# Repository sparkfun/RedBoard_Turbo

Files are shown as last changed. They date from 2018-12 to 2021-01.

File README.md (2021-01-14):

SparkFun RedBoard Turbo
========================================

SparkFun RedBoard Turbo

[*SparkFun RedBoard Turbo (DEV-14812)*](https://www.sparkfun.com/products/14812)

The RedBoard Turbo is an Arduino-sized breakout for the Atmel [ATSAMD21G18](http://www.atmel.com/devices/ATSAMD21G18A.aspx), a 32-bit ARM Cortex-M0+ processor with 4MB external flash, 32KB SRAM, and an operating speed of up to 48MHz. The SAMD21 is compatible with the Arduino IDE, and libraries for the Arduino Zero. With the UF2 bootloader, programming is easier than ever!

Repository Contents
-------------------

* **/Documentation** - Data sheets, additional product information
* **/Firmware** - UF2 Bootloader
* **/Hardware** - Eagle design files (.brd, .sch)
* **/Production** - Production panel files (.brd)

Documentation
--------------
* **[SparkFun Arduino Boards](https://github.com/sparkfun/Arduino_Boards)** - Arduino Boards.
* **[Hookup Guide](https://learn.sparkfun.com/tutorials/redboard-turbo-hookup-guide)** - Basic hookup guide for the RedBoard Turbo.
* **[SparkFun Fritzing Repo](https://github.com/sparkfun/Fritzing_Parts/blob/master/products/14812_sfe_redboard_turbo.fzpz)** - Fritzing diagrams for SparkFun products.
* **[SparkFun Graphical Datasheets](https://github.com/sparkfun/Graphical_Datasheets)** - Graphical Datasheets for various SparkFun products.

License Information
-------------------

This product is _**open source**_! 

Please review the LICENSE.md file for license information. 

If you have any questions or concerns on licensing, please contact technical support on our [SparkFun forums](https://forum.sparkfun.com/viewforum.php?f=152).

Distributed as-is; no warranty is given.

- Your friends at SparkFun.

_<COLLABORATION CREDIT>_

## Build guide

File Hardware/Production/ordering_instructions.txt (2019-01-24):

panel size, 204x175mm
PCB thickness, 1.6mm
number of layers, 2
soldermask color, Red
silkscreen color, White
oz copper, 1oz
finish, HASL lead free
stencils, none
pcs per panel, 9

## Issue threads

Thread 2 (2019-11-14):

dtostrf missing RedBoard_Turbo when it exists for Arduino Uno

alohawild, 2019-11-14:
I discovered I could not compile my code that coverts numbers to string. I had to instead find the code on the Internet and build it in myself. I think this should be built in.

Here is the code:

```
char * dtostrf(double number, signed char width, unsigned char prec, char *s) {

    if(isnan(number)) {
        strcpy(s, "nan");
        return s;
    }
    if(isinf(number)) {
        strcpy(s, "inf");
        return s;
    }

    if(number > 4294967040.0 || number < -4294967040.0) {
        strcpy(s, "ovf");
        return s;
    }
    char* out = s;
    // Handle negative numbers
    if(number < 0.0) {
        *out = '-';
        ++out;
        number = -number;
    }

    // Round correctly so that print(1.999, 2) prints as "2.00"
    double rounding = 0.5;
    for(uint8_t i = 0; i < prec; ++i)
        rounding /= 10.0;

    number += rounding;

    // Extract the integer part of the number and print it
    unsigned long int_part = (unsigned long) number;
    double remainder = number - (double) int_part;
    out += sprintf(out, "%d", int_part);

    // Print the decimal point, but only if there are digits beyond
    if(prec > 0) {
        *out = '.';
        ++out;
    }

    while(prec-- > 0) {
        remainder *= 10.0;
        if((int)remainder == 0){
                *out = '0';
                 ++out;
        }
    }
    sprintf(out, "%d", (int) remainder);

    return s;
}
```

awende, 2019-11-14:
The RedBoard Turbo uses the [uf2 bootloader](https://github.com/microsoft/uf2-samdx1) which was created and maintained by Microsoft. But looking into the issue I found that the dtostrf() function does not seem to work with any of the SAMD boards (tested with the Arduino/Genuino Zero board definition).

To get it working, you just need to add the library at the top of your sketch with any other libraries you may be using. Specifically, adding the following at the top of your sketch will get it to work.

`#include <avr/dtostrf.h>`

alohawild, 2019-11-14:
I like that better than copying in the code. Thanks for looking into this so fast. We can leave this as the solution so if anyone else has the issue they can see this here

Closed 2019-11-14.

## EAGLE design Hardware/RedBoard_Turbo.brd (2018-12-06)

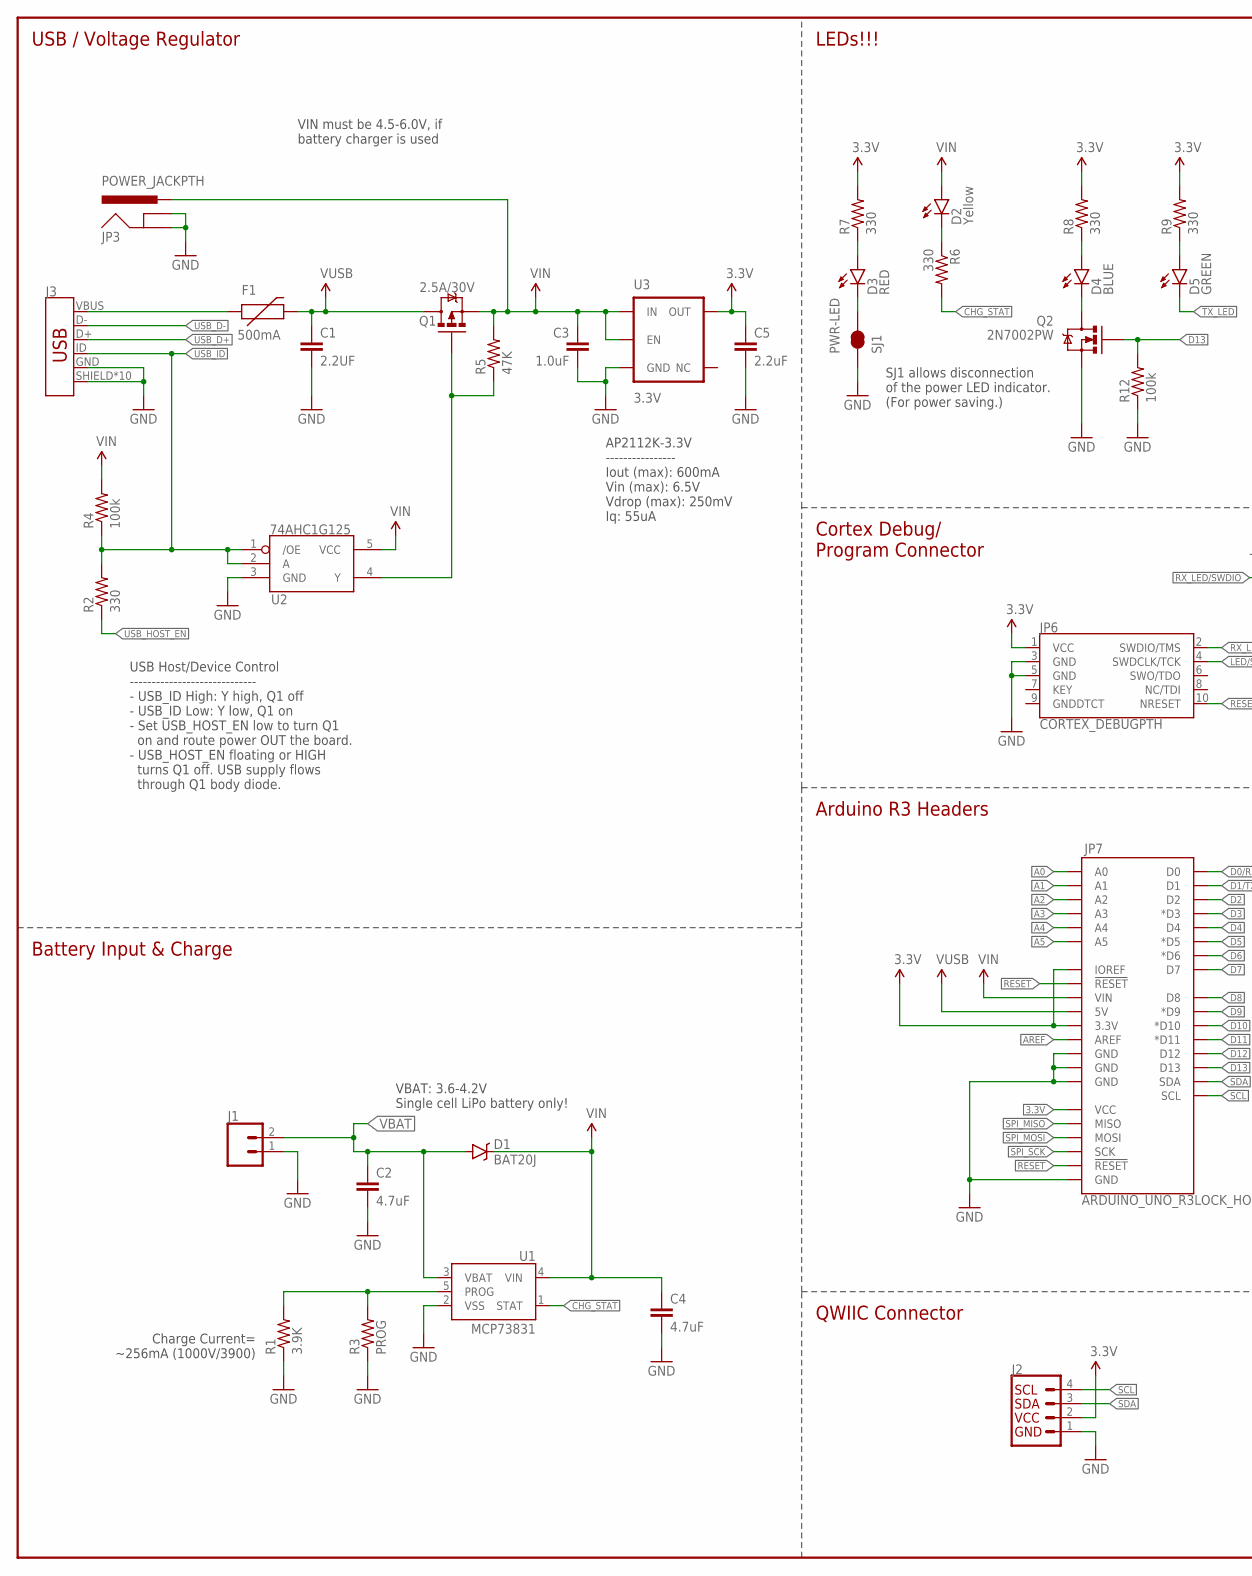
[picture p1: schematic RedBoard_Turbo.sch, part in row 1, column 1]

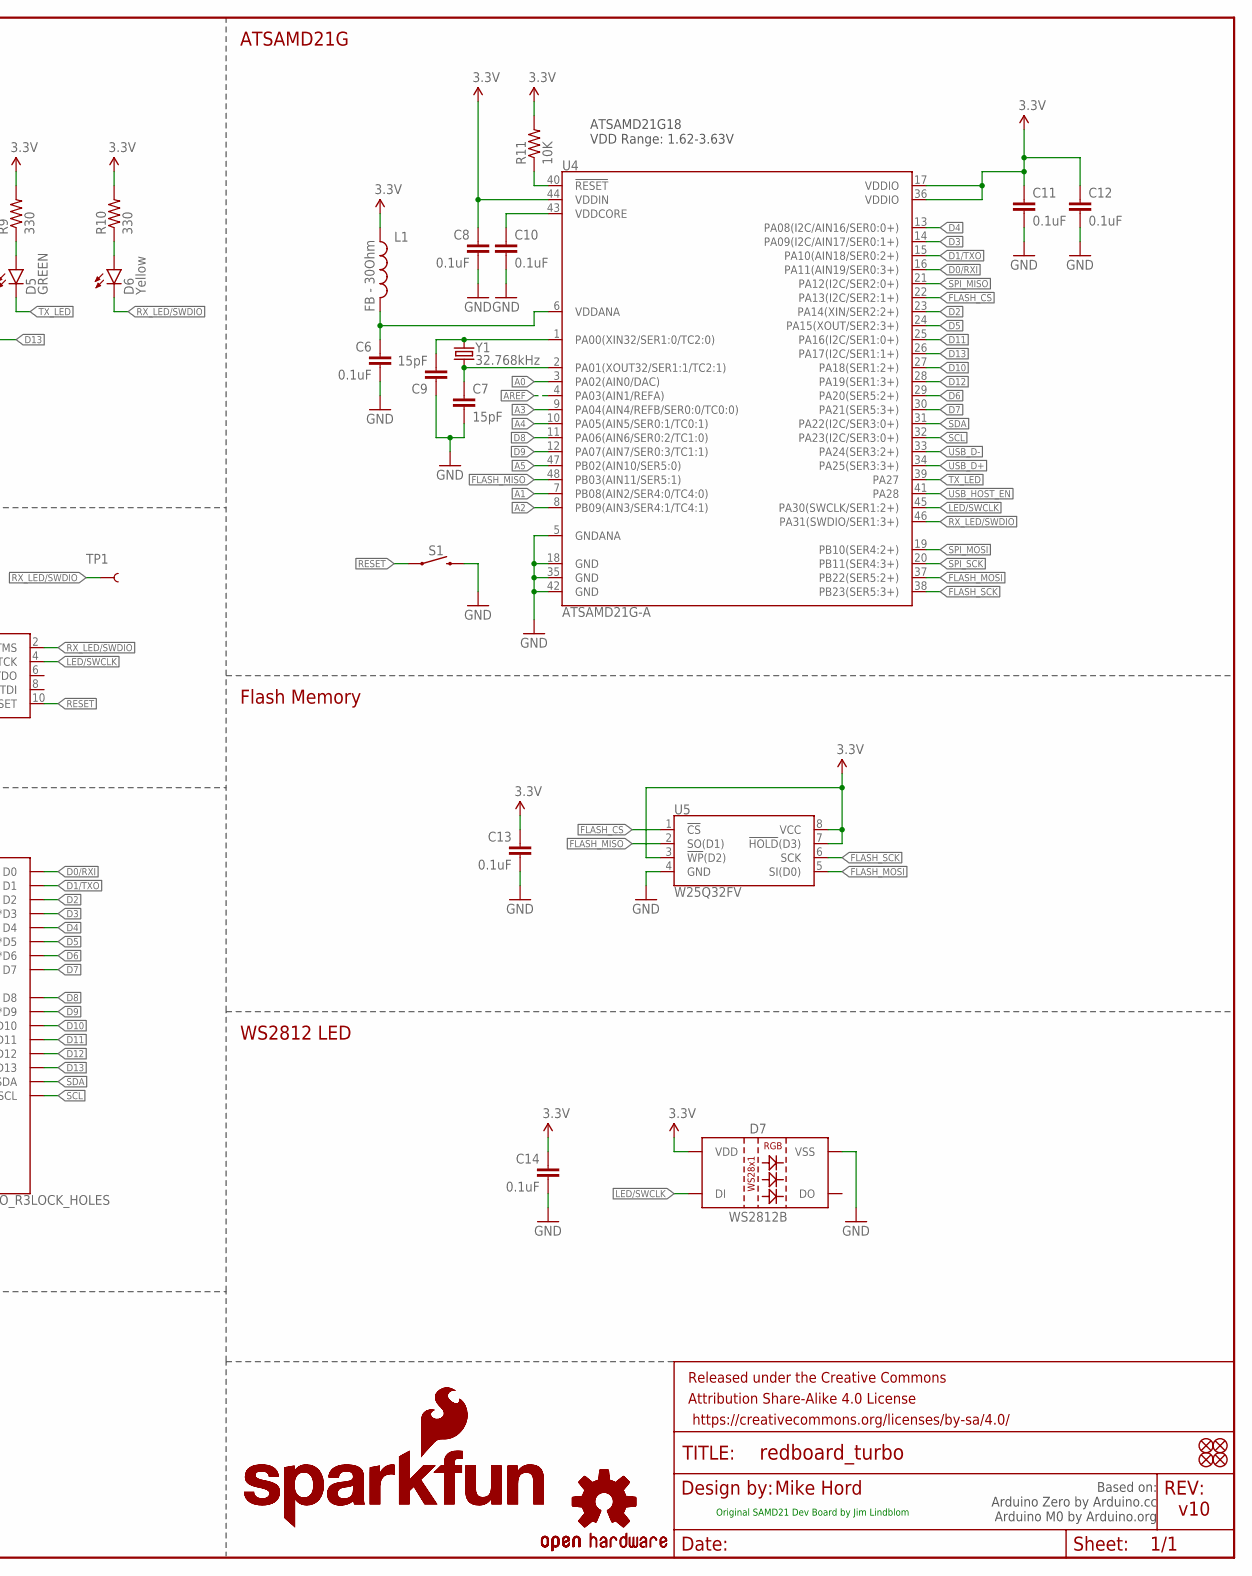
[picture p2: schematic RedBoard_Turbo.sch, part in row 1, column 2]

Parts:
C1: 2.2UF; 1206@1
C2, C4: 4.7uF; 0603-CAP
C3: 1.0uF; 0805
C5: 2.2uF; 0603-CAP
C6, C8, C10, C11, C12, C13, C14: 0.1uF; 0603-CAP
C7, C9: 15pF; 0603-CAP
D1: BAT20J; SOD-323
D2, D6: Yellow; LED-0603
D3: RED; LED-0603
D4: BLUE; LED-0603
D5: GREEN; LED-0603
D7: WS2812B
F1: 500mA; PTC-1206
FID1, FID2, FID3, FID4: FIDUCIAL1X2; FIDUCIAL-1X2
FRAME1: FRAME-LEDGER; CREATIVE_COMMONS
J1: CONN_02JST-PTH-2; JST-2-PTH
J2: QWIIC_CONNECTORJS-1MM; 1X04_1MM_RA
J3: USB_MICRO-B_HALF_PTH_MILL; USB-MICROB-PTH-MILL
JP3: POWER_JACKPTH; POWER_JACK_PTH
JP6: CORTEX_DEBUGPTH; 2X5-PTH-1.27MM
JP7: ARDUINO_UNO_R3LOCK_HOLES; ARDUINO_R3_LOCK_HOLES
L1: FB - 30Ohm; 0603
LOGO1: SFE_LOGO_NAME_FLAME.2_INCH; SFE_LOGO_NAME_FLAME_.2
LOGO2: SFE_LOGO_NAME_FLAME.3_INCH; SFE_LOGO_NAME_FLAME_.3
LOGO3: OSHW-LOGOS; OSHW-LOGO-S
LOGO4: OSHW-LOGOL; OSHW-LOGO-L
Q1: 2.5A/30V; SOT23-3
Q2: 2N7002PW; SOT323
R1: 3.9K; 0603
R2, R6, R7, R8, R9, R10: 330; 0603-RES
R3: PROG; 1/6W-RES
R4, R12: 100k; 0603-RES
R5: 47K; 0603-RES
R11: 10K; 0603-RES
S1: MOMENTARY-SWITCH-SPST-SMD-5.2-TALL-REDUNDANT; TACTILE_SWITCH_SMD_5.2MM
SJ1: PWR-LED; PAD-JUMPER-2-NC_BY_TRACE_NO_SILK
TP1: TEST-POINTTP_15TH_THRU; TP_15TH
U1: MCP73831; SOT23-5
U2: 74AHC1G125; SOT23-5
U3: 3.3V; SOT23-5
U4: ATSAMD21G-A; TQFP-48
U5: W25Q32FV; SOIC-8
Y1: 32.768kHz; CRYSTAL-SMD-3.2X1.5MM

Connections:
3.3V: C5.1, C8.1, C11.1, C12.1, C13.1, C14.1, D7.1 (VDD), J2.2, JP6.1 (VCC), JP7.3.3V, JP7.IOREF, JP7.VCC, L1.1, R7.2, R8.2, R9.2, R10.2, R11.2, U3.5 (OUT), U4.17 (VDDIO), U4.36 (VDDIO), U4.44 (VDDIN), U5.3 (!WP!(D2)), U5.7 (!HOLD!(D3)), U5.8 (VCC)
!RESET: JP6.10 (NRESET), JP7.RESET@1 (!RESET!), JP7.RESET@2 (!RESET!), R11.1, S1.1, S1.2 (1), U4.40 (!RESET!)
A0: JP7.A0, U4.3 (PA02(AIN0/DAC))
A1: JP7.A1, U4.7 (PB08(AIN2/SER4:0/TC4:0))
A2: JP7.A2, U4.8 (PB09(AIN3/SER4:1/TC4:1))
A3: JP7.A3, U4.9 (PA04(AIN4/REFB/SER0:0/TC0:0))
A4: JP7.A4, U4.10 (PA05(AIN5/SER0:1/TC0:1))
A5: JP7.A5, U4.47 (PB02(AIN10/SER5:0))
AREF: JP7.AREF, U4.4 (PA03(AIN1/REFA))
CHG_STAT: R6.2, U1.1 (STAT)
D0/RXI: JP7.D0, U4.16 (PA11(AIN19/SER0:3+))
D1/TXO: JP7.D1, U4.15 (PA10(AIN18/SER0:2+))
D2: JP7.D2, U4.23 (PA14(XIN/SER2:2+))
D3: JP7.D3 (*D3), U4.14 (PA09(I2C/AIN17/SER0:1+))
D4: JP7.D4, U4.13 (PA08(I2C/AIN16/SER0:0+))
D5: JP7.D5 (*D5), U4.24 (PA15(XOUT/SER2:3+))
D6: JP7.D6 (*D6), U4.29 (PA20(SER5:2+))
D7: JP7.D7, U4.30 (PA21(SER5:3+))
D8: JP7.D8, U4.11 (PA06(AIN6/SER0:2/TC1:0))
D9: JP7.D9 (*D9), U4.12 (PA07(AIN7/SER0:3/TC1:1))
D10: JP7.D10 (*D10), U4.27 (PA18(SER1:2+))
D11: JP7.D11 (*D11), U4.25 (PA16(I2C/SER1:0+))
D12: JP7.D12, U4.28 (PA19(SER1:3+))
D13: JP7.D13, Q2.1 (G), R12.2, U4.26 (PA17(I2C/SER1:1+))
FLASH_CS: U4.22 (PA13(I2C/SER2:1+)), U5.1 (!CS!)
FLASH_MISO: U4.48 (PB03(AIN11/SER5:1)), U5.2 (SO(D1))
FLASH_MOSI: U4.37 (PB22(SER5:2+)), U5.5 (SI(D0))
FLASH_SCK: U4.38 (PB23(SER5:3+)), U5.6 (SCK)
GND: C1.2, C2.2, C3.2, C4.2, C5.2, C6.2, C7.2, C8.2, C9.1, C10.2, C11.2, C12.2, C13.2, C14.2, D7.3 (VSS), J1.1, J2.1, J3.GND, J3.SHIELD, J3.SHIELD2 (SHIELD), J3.SHIELD3 (SHIELD), J3.SHIELD4 (SHIELD), J3.SHIELD5 (SHIELD), J3.SHIELD6 (SHIELD), J3.SHIELD7 (SHIELD), J3.SHIELD8 (SHIELD), J3.SHIELD9 (SHIELD), J3.SHIELD10 (SHIELD), JP3.GND, JP3.GNDBREAK, JP6.3 (GND), JP6.5 (GND), JP7.GND@1 (GND), JP7.GND@2 (GND), JP7.GND@3 (GND), JP7.GND@4 (GND), Q2.2 (S), R1.1, R3.1, R12.1, S1.3 (2), S1.4 (2), SJ1.1, U1.2 (VSS), U2.3 (GND), U3.2 (GND), U4.5 (GNDANA), U4.18 (GND), U4.35 (GND), U4.42 (GND), U5.4 (GND)
LED/SWCLK: D7.4 (DI), JP6.4 (SWDCLK/TCK), U4.45 (PA30(SWCLK/SER1:2+))
unnamed: F1.1, J3.VBUS
unnamed: C9.2, U4.1 (PA00(XIN32/SER1:0/TC2:0)), Y1.P$2 (2)
unnamed: D4.C, Q2.3 (D)
unnamed: C7.1, U4.2 (PA01(XOUT32/SER1:1/TC2:1)), Y1.P$1 (1)
unnamed: D3.A, R7.1
unnamed: D4.A, R8.1
unnamed: D2.C, R6.1
unnamed: D5.A, R9.1
unnamed: D6.A, R10.1
unnamed: D3.C, SJ1.2
unnamed: R1.2, R3.2, U1.5 (PROG)
RX_LED/SWDIO: D6.C, JP6.2 (SWDIO/TMS), TP1.P$1, U4.46 (PA31(SWDIO/SER1:3+))
SCL: J2.4, JP7.SCL, U4.32 (PA23(I2C/SER3:0+))
SDA: J2.3, JP7.SDA, U4.31 (PA22(I2C/SER3:0+))
SPI_MISO: JP7.MISO, U4.21 (PA12(I2C/SER2:0+))
SPI_MOSI: JP7.MOSI, U4.19 (PB10(SER4:2+))
SPI_SCK: JP7.SCK, U4.20 (PB11(SER4:3+))
TX_LED: D5.C, U4.39 (PA27)
USB_D+: J3.D+, U4.34 (PA25(SER3:3+))
USB_D-: J3.D-, U4.33 (PA24(SER3:2+))
USB_HOST_EN: R2.1, U4.41 (PA28)
USB_HOST_POWER_EN: Q1.1 (G), R5.1, U2.4 (Y)
USB_ID: J3.ID, R2.2, R4.1, U2.1 (/OE), U2.2 (A)
VBAT: C2.1, D1.A, J1.2, U1.3 (VBAT)
VDDANA: C6.1, L1.2, U4.6 (VDDANA)
VDDCORE: C10.1, U4.43 (VDDCORE)
VIN: C3.1, C4.1, D1.C, D2.A, JP3.PWR, JP7.VIN, Q1.2 (S), R4.2, R5.2, U1.4 (VIN), U2.5 (VCC), U3.1 (IN), U3.3 (EN)
VUSB: C1.1, F1.2, JP7.5V, Q1.3 (D)

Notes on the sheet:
USB / Voltage Regulator
LEDs!!!
Cortex Debug/ Program Connector
Arduino R3 Headers
ATSAMD21G
Mike Hord
v10
Charge Current= ~256mA (1000V/3900)
Battery Input & Charge
SJ1 allows disconnection of the power LED indicator. (For power saving.)
VIN must be 4.5-6.0V, if battery charger is used
ATSAMD21G18 VDD Range: 1.62-3.63V
Based on: Arduino Zero by Arduino.cc Arduino M0 by Arduino.org
AP2112K-3.3V ---------------- Iout (max): 600mA Vin (max): 6.5V Vdrop (max): 250mV Iq: 55uA
USB Host/Device Control ----------------------------- - USB_ID High: Y high, Q1 off - USB_ID Low: Y low, Q1 on - Set USB_HOST_EN low to turn Q1 on and route power OUT the board. - USB_HOST_EN floating or HIGH turns Q1 off. USB supply flows through Q1 body diode.
VBAT: 3.6-4.2V Single cell LiPo battery only\!
QWIIC Connector
WS2812 LED
Flash Memory
Original SAMD21 Dev Board by Jim Lindblom

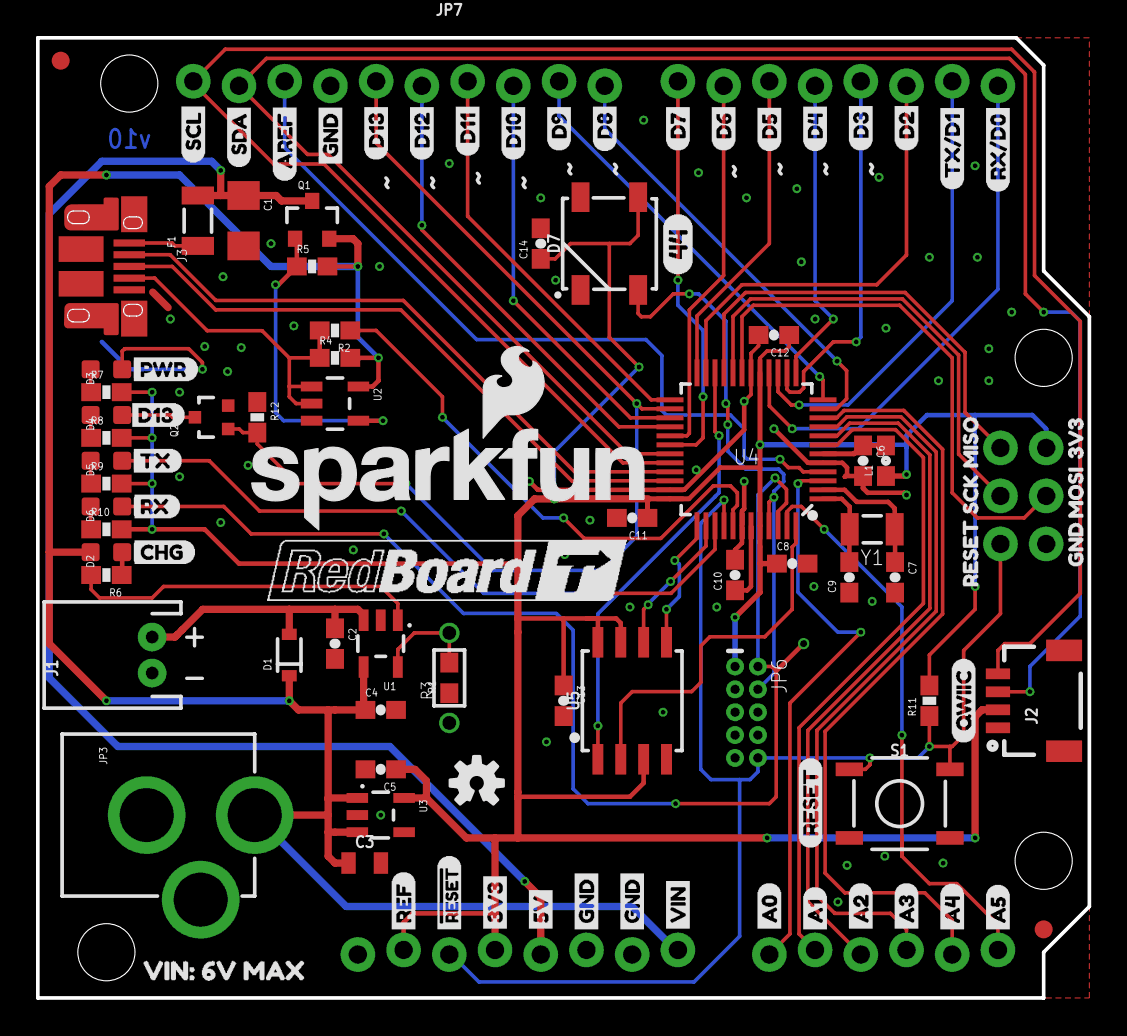
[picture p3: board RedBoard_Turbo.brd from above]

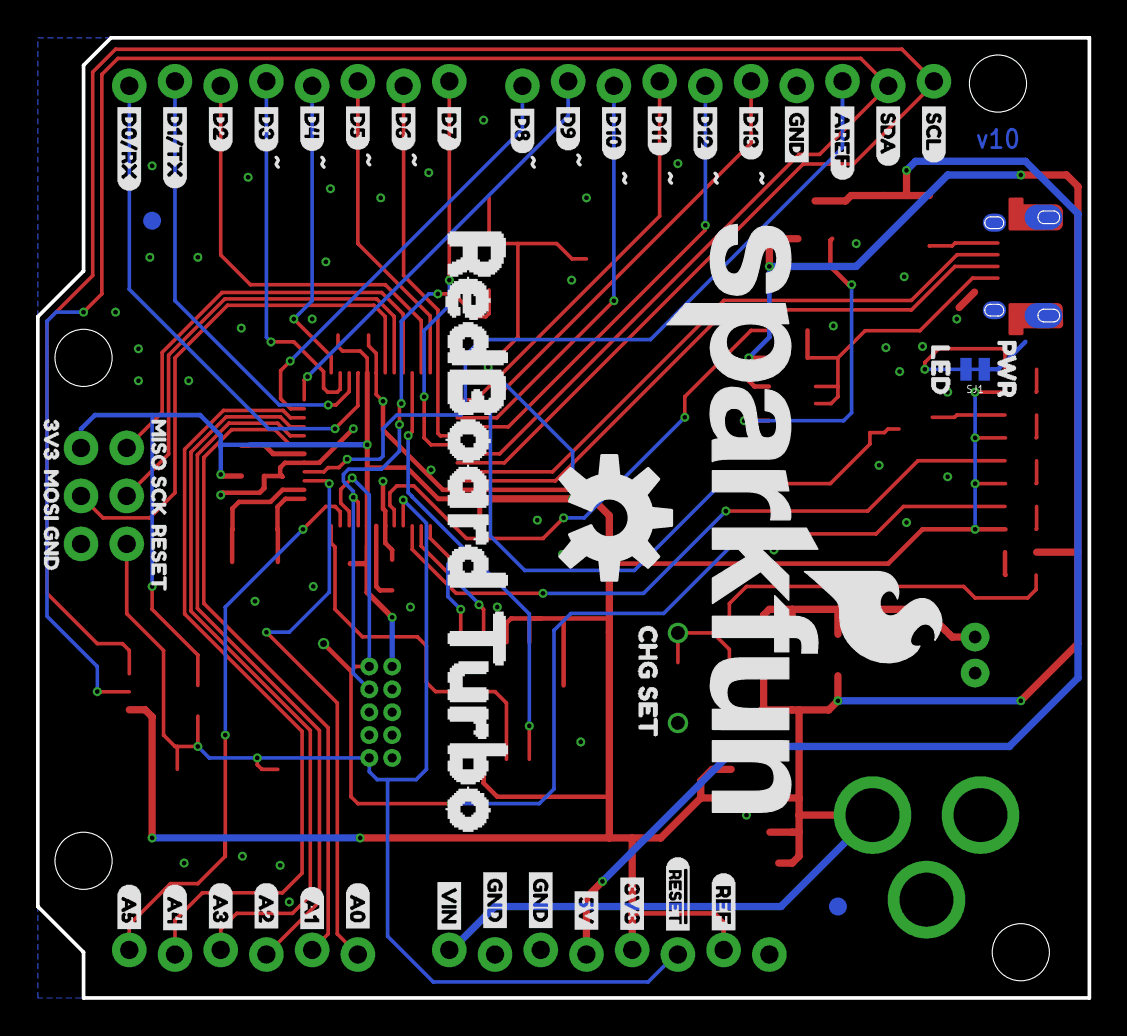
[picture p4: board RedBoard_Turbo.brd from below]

Board: 2 copper layers, 58.4 x 53.3 mm, 149 parts (46 on the bottom side), 58 nets.

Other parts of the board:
U$1, U$44: #RESET1
U$2: 3V317
U$3: 5V18
U$4: CHG30
U$5: RX#D015
U$6: TX#D114
U$7: D213
U$8: D312
U$9: D411
U$10: D510
U$11: D69
U$12: D78
U$13: D87
U$14: D96
U$15: D105
U$16: D114
U$17: D123
U$18: D132
U$19, U$36, U$37: GND16
U$20, U$81: SDA1
U$21, U$80: SCL0
U$22: TX28
U$23: RX29
U$24: PWR26
U$25: D1327
U$26: REF0
U$27, U$53: AREF2
U$28: QWIIC31
U$29: A020
U$30: A121
U$31: A222
U$32: A323
U$33: A424
U$34: A525
U$35: VIN19
U$38: GND7
U$39: MOSI4
U$40: 3V36
U$41: SCK5
U$42: MISO3
U$43, U$83: RESET0
U$45: 3V325
U$46: 3V30
U$47: A018
U$48: A119
U$49: A220
U$50: A321
U$51: A422
U$52: A523
U$54: LED1
U$55: D0#RX17
U$56: D1#TX15
U$57: 5V26
U$58: D79
U$59: D88
U$60: D97
U$61: D106
U$62: D115
U$63: D124
U$64: D133
U$65: D214
U$66: D313
U$67: D412
U$68: D511
U$69: D610
U$70, U$71, U$72: GND24
U$73: GND33
U$74: PWR0
U$75: MISO30
U$76: MOSI34
U$77: REF28
U$78: RESET32
U$79: SCK31
U$82: VIN27
U$84: 440
U$85: REDBOARD_TURBO1
U$86: BITMAP#JPG
U$87: CHG_SET1
U$88: VIN#_6V_MAX2

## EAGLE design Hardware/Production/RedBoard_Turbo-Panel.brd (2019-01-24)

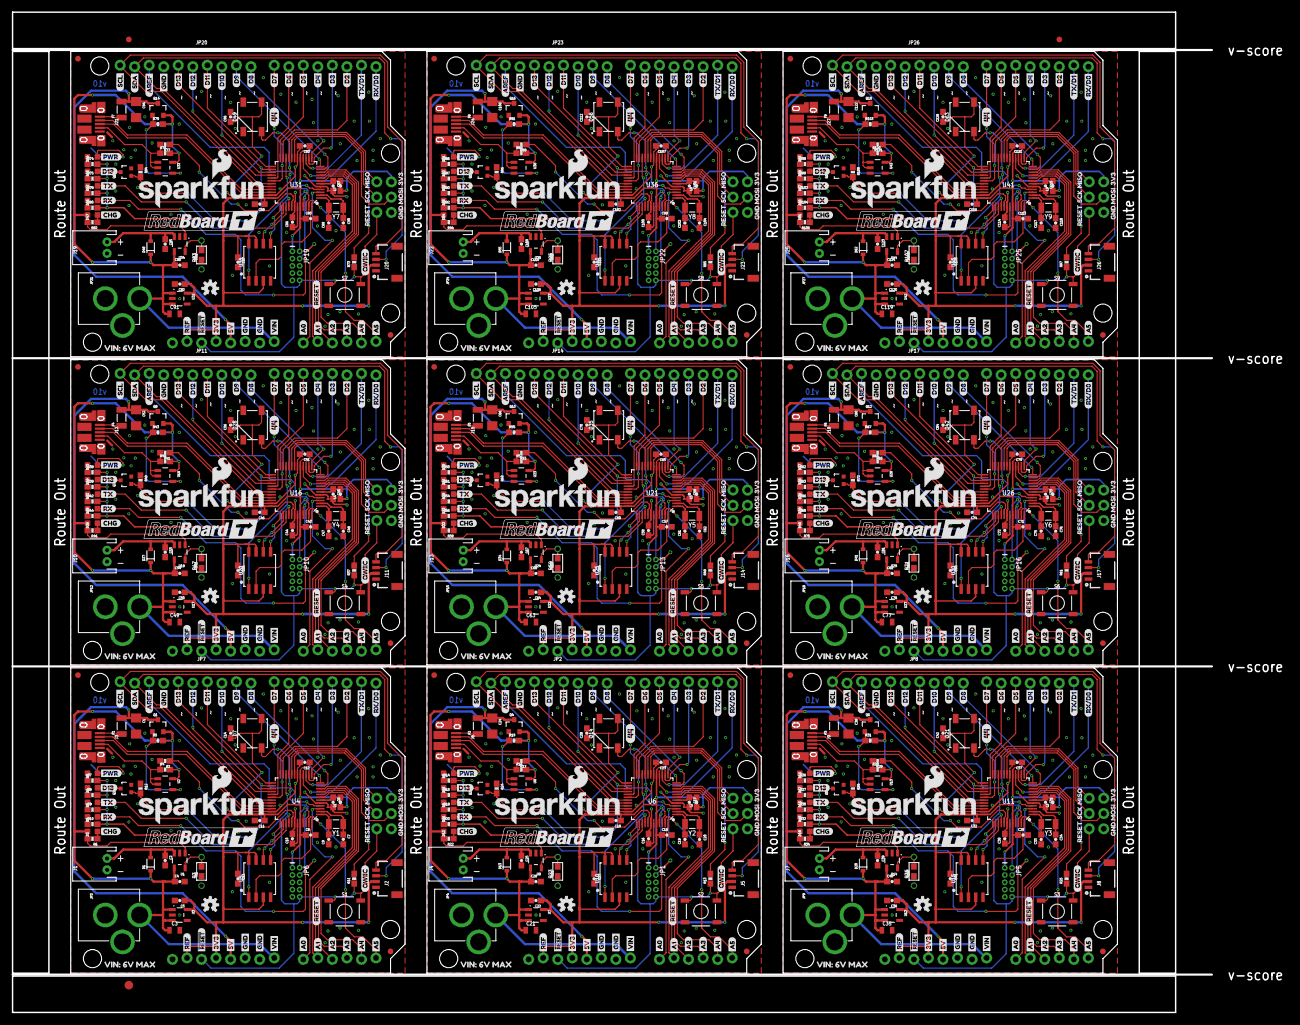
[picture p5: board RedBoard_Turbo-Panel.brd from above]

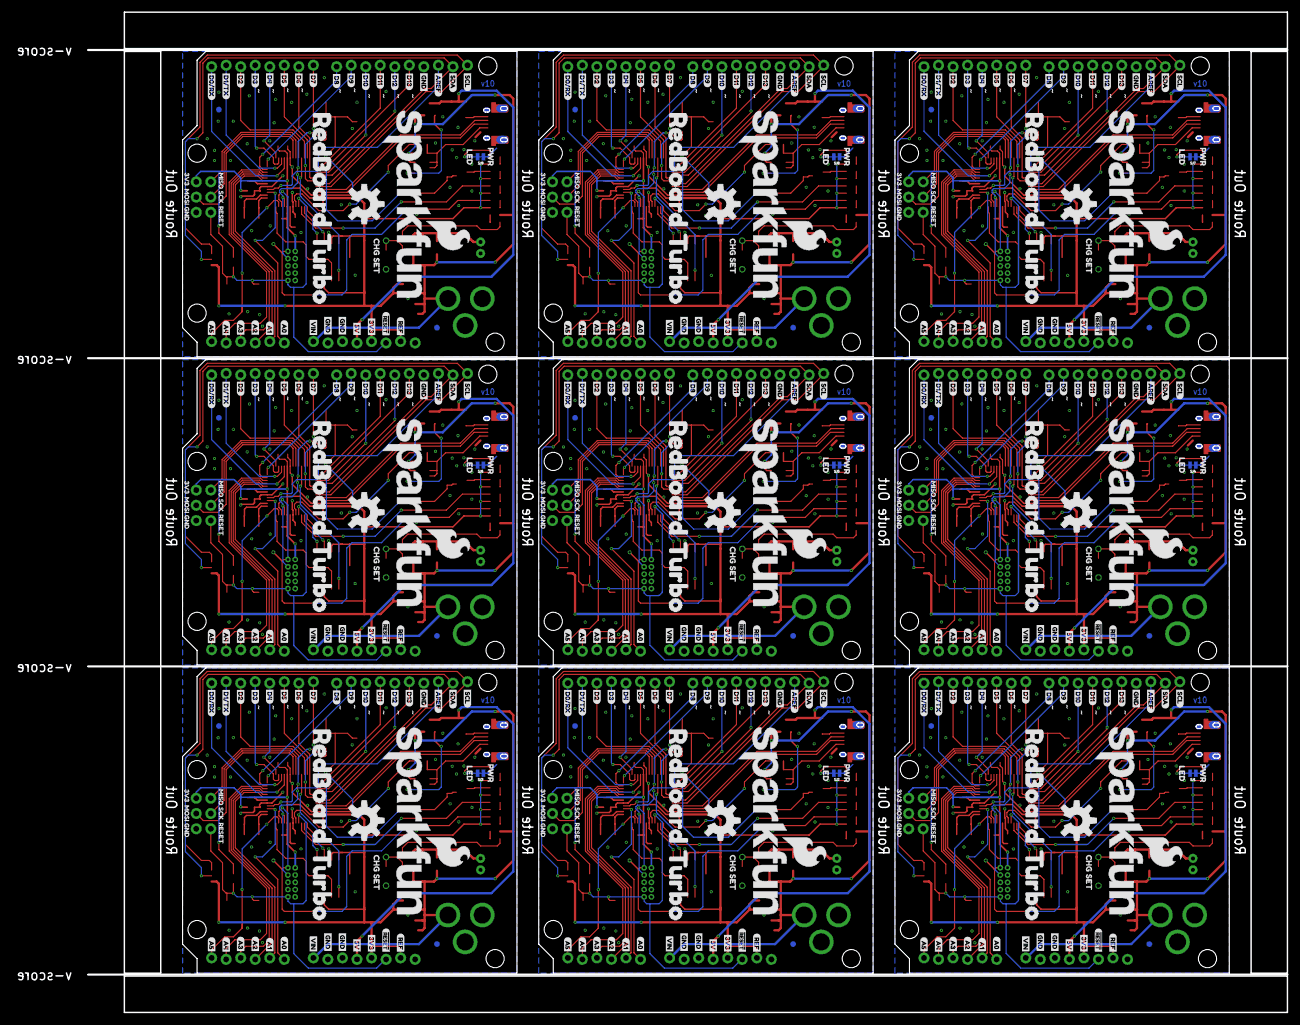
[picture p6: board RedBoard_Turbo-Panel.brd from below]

Board: 2 copper layers, 209.5 x 174.8 mm, 1335 parts (414 on the bottom side), 522 nets.

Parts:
C1, C24, C38, C52, C66, C80, C94, C108, C122: 2.2UF; 1206@1
C2, C4, C25, C26, C39, C40, C53, C54, C67, C68, C81, C82, C95, C96, C109, C110, C123, C124: 4.7uF; 0603-CAP
C3, C21, C35, C49, C63, C77, C91, C105, C119: 1.0uF; 0805
C5, C22, C36, C50, C64, C78, C92, C106, C120: 2.2uF; 0603-CAP
C6, C8, C10, C11, C12, C13, C14, C15, C16, C17, C18, C23, C27, C28, C29, C30, C31, C32, C37, C41, C42, C43, C44, C45, C46, C51, C55, C56, C57, C58, C59, C60, C65, C69, C70, C71, C72, C73, C74, C79, C83, C84, C85, C86, C87, C88, C93, C97, C98, C99, C100, C101, C102, C107, C111, C112, C113, C114, C115, C116, C121, C125, C126: 0.1uF; 0603-CAP
C7, C9, C19, C20, C33, C34, C47, C48, C61, C62, C75, C76, C89, C90, C103, C104, C117, C118: 15pF; 0603-CAP
D1, D13, D20, D27, D34, D41, D48, D55, D62: BAT20J; SOD-323
D2, D6, D11, D12, D18, D19, D25, D26, D32, D33, D39, D40, D46, D47, D53, D54, D60, D61: Yellow; LED-0603
D3, D9, D16, D23, D30, D37, D44, D51, D58: RED; LED-0603
D4, D10, D17, D24, D31, D38, D45, D52, D59: BLUE; LED-0603
D5, D8, D15, D22, D29, D36, D43, D50, D57: GREEN; LED-0603
D7, D14, D21, D28, D35, D42, D49, D56, D63: WS2812B
E$1, E$2: FIDUCIAL-1X2
E$3: FIDUCIAL-1.5X3
F1, F2, F3, F4, F5, F6, F7, F8, F9: 500mA; PTC-1206
FID1, FID2, FID3, FID4, FID5, FID6, FID7, FID8, FID9, FID10, FID11, FID12, FID13, FID14, FID15, FID16, FID17, FID18, FID19, FID20, FID21, FID22, FID23, FID24, FID25, FID26, FID27, FID28, FID29, FID30, FID31, FID32, FID33, FID34, FID35, FID36: FIDUCIAL1X2; FIDUCIAL-1X2
J1, J4, J7, J10, J13, J16, J19, J22, J25: JST-2-PTH
J2, J5, J8, J11, J14, J17, J20, J23, J26: 1X04_1MM_RA
J3, J6, J9, J12, J15, J18, J21, J24, J27: USB-MICROB-PTH-MILL
JP1, JP5, JP6, JP10, JP13, JP16, JP19, JP22, JP25: CORTEX_DEBUGPTH; 2X5-PTH-1.27MM
JP2, JP7, JP8, JP11, JP14, JP17, JP20, JP23, JP26: ARDUINO_UNO_R3LOCK_HOLES; ARDUINO_R3_LOCK_HOLES
JP3, JP4, JP9, JP12, JP15, JP18, JP21, JP24, JP27: POWER_JACKPTH; POWER_JACK_PTH
L1, L2, L3, L4, L5, L6, L7, L8, L9: FB - 30Ohm; 0603
LOGO1, LOGO6, LOGO10, LOGO14, LOGO18, LOGO22, LOGO26, LOGO30, LOGO34: SFE_LOGO_NAME_FLAME.2_INCH; SFE_LOGO_NAME_FLAME_.2
LOGO2, LOGO7, LOGO11, LOGO15, LOGO19, LOGO23, LOGO27, LOGO31, LOGO35: SFE_LOGO_NAME_FLAME.3_INCH; SFE_LOGO_NAME_FLAME_.3
LOGO3, LOGO5, LOGO9, LOGO13, LOGO17, LOGO21, LOGO25, LOGO29, LOGO33: OSHW-LOGOS; OSHW-LOGO-S
LOGO4, LOGO8, LOGO12, LOGO16, LOGO20, LOGO24, LOGO28, LOGO32, LOGO36: OSHW-LOGOL; OSHW-LOGO-L
Q1, Q4, Q6, Q8, Q10, Q12, Q14, Q16, Q18: 2.5A/30V; SOT23-3
Q2, Q3, Q5, Q7, Q9, Q11, Q13, Q15, Q17: 2N7002PW; SOT323
R1, R21, R33, R45, R57, R69, R81, R93, R105: 3.9K; 0603
R2, R6, R7, R8, R9, R10, R14, R15, R17, R18, R20, R22, R26, R27, R29, R30, R32, R34, R38, R39, R41, R42, R44, R46, R50, R51, R53, R54, R56, R58, R62, R63, R65, R66, R68, R70, R74, R75, R77, R78, R80, R82, R86, R87, R89, R90, R92, R94, R98, R99, R101, R102, R104, R106: 330; 0603-RES
R3, R23, R35, R47, R59, R71, R83, R95, R107: PROG; 1/6W-RES
R4, R12, R16, R24, R28, R36, R40, R48, R52, R60, R64, R72, R76, R84, R88, R96, R100, R108: 100k; 0603-RES
R5, R19, R31, R43, R55, R67, R79, R91, R103: 47K; 0603-RES
R11, R13, R25, R37, R49, R61, R73, R85, R97: 10K; 0603-RES
S1, S2, S3, S4, S5, S6, S7, S8, S9: TACTILE_SWITCH_SMD_5.2MM
SJ1, SJ2, SJ3, SJ4, SJ5, SJ6, SJ7, SJ8, SJ9: PWR-LED; PAD-JUMPER-2-NC_BY_TRACE_NO_SILK
TP1, TP2, TP3, TP4, TP5, TP6, TP7, TP8, TP9: TEST-POINTTP_15TH_THRU; TP_15TH
U1, U9, U14, U19, U24, U29, U34, U39, U44: MCP73831; SOT23-5
U2, U8, U13, U18, U23, U28, U33, U38, U43: 74AHC1G125; SOT23-5
U3, U7, U12, U17, U22, U27, U32, U37, U42: 3.3V; SOT23-5
U4, U6, U11, U16, U21, U26, U31, U36, U41: ATSAMD21G-A; TQFP-48
U5, U10, U15, U20, U25, U30, U35, U40, U45: W25Q32FV; SOIC-8
U$1, U$44, U$123, U$166, U$211, U$254, U$299, U$342, U$387, U$430, U$475, U$518, U$563, U$606, U$651, U$694, U$739, U$782: #RESET1
U$2, U$89, U$177, U$265, U$353, U$441, U$529, U$617, U$705: 3V317
U$3, U$90, U$178, U$266, U$354, U$442, U$530, U$618, U$706: 5V18
U$4, U$91, U$179, U$267, U$355, U$443, U$531, U$619, U$707: CHG30
U$5, U$92, U$180, U$268, U$356, U$444, U$532, U$620, U$708: RX#D015
U$6, U$93, U$181, U$269, U$357, U$445, U$533, U$621, U$709: TX#D114
U$7, U$94, U$182, U$270, U$358, U$446, U$534, U$622, U$710: D213
U$8, U$95, U$183, U$271, U$359, U$447, U$535, U$623, U$711: D312
U$9, U$96, U$184, U$272, U$360, U$448, U$536, U$624, U$712: D411
U$10, U$97, U$185, U$273, U$361, U$449, U$537, U$625, U$713: D510
U$11, U$98, U$186, U$274, U$362, U$450, U$538, U$626, U$714: D69
U$12, U$99, U$187, U$275, U$363, U$451, U$539, U$627, U$715: D78
U$13, U$100, U$188, U$276, U$364, U$452, U$540, U$628, U$716: D87
U$14, U$101, U$189, U$277, U$365, U$453, U$541, U$629, U$717: D96
U$15, U$102, U$190, U$278, U$366, U$454, U$542, U$630, U$718: D105
U$16, U$103, U$191, U$279, U$367, U$455, U$543, U$631, U$719: D114
U$17, U$104, U$192, U$280, U$368, U$456, U$544, U$632, U$720: D123
U$18, U$105, U$193, U$281, U$369, U$457, U$545, U$633, U$721: D132
U$19, U$36, U$37, U$106, U$121, U$122, U$194, U$209, U$210, U$282, U$297, U$298, U$370, U$385, U$386, U$458, U$473, U$474, U$546, U$561, U$562, U$634, U$649, U$650, U$722, U$737, U$738: GND16
U$20, U$81, U$107, U$164, U$195, U$252, U$283, U$340, U$371, U$428, U$459, U$516, U$547, U$604, U$635, U$692, U$723, U$780: SDA1
U$21, U$80, U$108, U$163, U$196, U$251, U$284, U$339, U$372, U$427, U$460, U$515, U$548, U$603, U$636, U$691, U$724, U$779: SCL0
U$22, U$109, U$197, U$285, U$373, U$461, U$549, U$637, U$725: TX28
U$23, U$110, U$198, U$286, U$374, U$462, U$550, U$638, U$726: RX29
U$24, U$111, U$199, U$287, U$375, U$463, U$551, U$639, U$727: PWR26
U$25, U$112, U$200, U$288, U$376, U$464, U$552, U$640, U$728: D1327
U$26, U$124, U$212, U$300, U$388, U$476, U$564, U$652, U$740: REF0
U$27, U$53, U$125, U$139, U$213, U$227, U$301, U$315, U$389, U$403, U$477, U$491, U$565, U$579, U$653, U$667, U$741, U$755: AREF2
U$28, U$113, U$201, U$289, U$377, U$465, U$553, U$641, U$729: QWIIC31
U$29, U$114, U$202, U$290, U$378, U$466, U$554, U$642, U$730: A020
U$30, U$115, U$203, U$291, U$379, U$467, U$555, U$643, U$731: A121
U$31, U$116, U$204, U$292, U$380, U$468, U$556, U$644, U$732: A222
U$32, U$117, U$205, U$293, U$381, U$469, U$557, U$645, U$733: A323
U$33, U$118, U$206, U$294, U$382, U$470, U$558, U$646, U$734: A424
U$34, U$119, U$207, U$295, U$383, U$471, U$559, U$647, U$735: A525
U$35, U$120, U$208, U$296, U$384, U$472, U$560, U$648, U$736: VIN19
U$38, U$126, U$214, U$302, U$390, U$478, U$566, U$654, U$742: GND7
U$39, U$127, U$215, U$303, U$391, U$479, U$567, U$655, U$743: MOSI4
U$40, U$128, U$216, U$304, U$392, U$480, U$568, U$656, U$744: 3V36
U$41, U$129, U$217, U$305, U$393, U$481, U$569, U$657, U$745: SCK5
U$42, U$130, U$218, U$306, U$394, U$482, U$570, U$658, U$746: MISO3
U$43, U$83, U$131, U$169, U$219, U$257, U$307, U$345, U$395, U$433, U$483, U$521, U$571, U$609, U$659, U$697, U$747, U$785: RESET0
U$45, U$132, U$220, U$308, U$396, U$484, U$572, U$660, U$748: 3V325
U$46, U$167, U$255, U$343, U$431, U$519, U$607, U$695, U$783: 3V30
U$47, U$133, U$221, U$309, U$397, U$485, U$573, U$661, U$749: A018
U$48, U$134, U$222, U$310, U$398, U$486, U$574, U$662, U$750: A119
U$49, U$135, U$223, U$311, U$399, U$487, U$575, U$663, U$751: A220
U$50, U$136, U$224, U$312, U$400, U$488, U$576, U$664, U$752: A321
U$51, U$137, U$225, U$313, U$401, U$489, U$577, U$665, U$753: A422
U$52, U$138, U$226, U$314, U$402, U$490, U$578, U$666, U$754: A523
U$54, U$174, U$262, U$350, U$438, U$526, U$614, U$702, U$790: LED1
U$55, U$140, U$228, U$316, U$404, U$492, U$580, U$668, U$756: D0#RX17
U$56, U$141, U$229, U$317, U$405, U$493, U$581, U$669, U$757: D1#TX15
U$57, U$168, U$256, U$344, U$432, U$520, U$608, U$696, U$784: 5V26
U$58, U$142, U$230, U$318, U$406, U$494, U$582, U$670, U$758: D79
U$59, U$143, U$231, U$319, U$407, U$495, U$583, U$671, U$759: D88
U$60, U$144, U$232, U$320, U$408, U$496, U$584, U$672, U$760: D97
U$61, U$145, U$233, U$321, U$409, U$497, U$585, U$673, U$761: D106
U$62, U$146, U$234, U$322, U$410, U$498, U$586, U$674, U$762: D115
U$63, U$147, U$235, U$323, U$411, U$499, U$587, U$675, U$763: D124
U$64, U$148, U$236, U$324, U$412, U$500, U$588, U$676, U$764: D133
U$65, U$149, U$237, U$325, U$413, U$501, U$589, U$677, U$765: D214
U$66, U$150, U$238, U$326, U$414, U$502, U$590, U$678, U$766: D313
U$67, U$151, U$239, U$327, U$415, U$503, U$591, U$679, U$767: D412
U$68, U$152, U$240, U$328, U$416, U$504, U$592, U$680, U$768: D511
U$69, U$153, U$241, U$329, U$417, U$505, U$593, U$681, U$769: D610
U$70, U$71, U$72, U$154, U$155, U$156, U$242, U$243, U$244, U$330, U$331, U$332, U$418, U$419, U$420, U$506, U$507, U$508, U$594, U$595, U$596, U$682, U$683, U$684, U$770, U$771, U$772: GND24
U$73, U$157, U$245, U$333, U$421, U$509, U$597, U$685, U$773: GND33
U$74, U$175, U$263, U$351, U$439, U$527, U$615, U$703, U$791: PWR0
U$75, U$158, U$246, U$334, U$422, U$510, U$598, U$686, U$774: MISO30
U$76, U$159, U$247, U$335, U$423, U$511, U$599, U$687, U$775: MOSI34
U$77, U$160, U$248, U$336, U$424, U$512, U$600, U$688, U$776: REF28
U$78, U$161, U$249, U$337, U$425, U$513, U$601, U$689, U$777: RESET32
U$79, U$162, U$250, U$338, U$426, U$514, U$602, U$690, U$778: SCK31
U$82, U$165, U$253, U$341, U$429, U$517, U$605, U$693, U$781: VIN27
U$84, U$171, U$259, U$347, U$435, U$523, U$611, U$699, U$787: 440
U$85, U$172, U$260, U$348, U$436, U$524, U$612, U$700, U$788: REDBOARD_TURBO1
U$86, U$170, U$258, U$346, U$434, U$522, U$610, U$698, U$786: BITMAP#JPG
U$87, U$173, U$261, U$349, U$437, U$525, U$613, U$701, U$789: CHG_SET1
U$88, U$176, U$264, U$352, U$440, U$528, U$616, U$704, U$792: VIN#_6V_MAX2
Y1, Y2, Y3, Y4, Y5, Y6, Y7, Y8, Y9: 32.768kHz; CRYSTAL-SMD-3.2X1.5MM

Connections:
3.3V: C5.1, C8.1, C11.1, C12.1, C13.1, C14.1, D7.1, J2.2, JP6.1, JP7.3.3V, JP7.IOREF, JP7.VCC, L1.1, R7.2, R8.2, R9.2, R10.2, R11.2, U3.5, U4.17, U4.36, U4.44, U5.3, U5.7, U5.8
3.3V1: C15.1, C18.1, C22.1, C23.1, C27.1, C28.1, D14.1, J5.2, JP1.1, JP2.3.3V, JP2.IOREF, JP2.VCC, L2.1, R13.2, R14.2, R15.2, R18.2, R20.2, U6.17, U6.36, U6.44, U7.5, U10.3, U10.7, U10.8
3.3V2: C29.1, C32.1, C36.1, C37.1, C41.1, C42.1, D21.1, J8.2, JP5.1, JP8.3.3V, JP8.IOREF, JP8.VCC, L3.1, R25.2, R26.2, R27.2, R30.2, R32.2, U11.17, U11.36, U11.44, U12.5, U15.3, U15.7, U15.8
3.3V3: C43.1, C46.1, C50.1, C51.1, C55.1, C56.1, D28.1, J11.2, JP10.1, JP11.3.3V, JP11.IOREF, JP11.VCC, L4.1, R37.2, R38.2, R39.2, R42.2, R44.2, U16.17, U16.36, U16.44, U17.5, U20.3, U20.7, U20.8
3.3V4: C57.1, C60.1, C64.1, C65.1, C69.1, C70.1, D35.1, J14.2, JP13.1, JP14.3.3V, JP14.IOREF, JP14.VCC, L5.1, R49.2, R50.2, R51.2, R54.2, R56.2, U21.17, U21.36, U21.44, U22.5, U25.3, U25.7, U25.8
3.3V5: C71.1, C74.1, C78.1, C79.1, C83.1, C84.1, D42.1, J17.2, JP16.1, JP17.3.3V, JP17.IOREF, JP17.VCC, L6.1, R61.2, R62.2, R63.2, R66.2, R68.2, U26.17, U26.36, U26.44, U27.5, U30.3, U30.7, U30.8
3.3V6: C85.1, C88.1, C92.1, C93.1, C97.1, C98.1, D49.1, J20.2, JP19.1, JP20.3.3V, JP20.IOREF, JP20.VCC, L7.1, R73.2, R74.2, R75.2, R78.2, R80.2, U31.17, U31.36, U31.44, U32.5, U35.3, U35.7, U35.8
3.3V7: C99.1, C102.1, C106.1, C107.1, C111.1, C112.1, D56.1, J23.2, JP22.1, JP23.3.3V, JP23.IOREF, JP23.VCC, L8.1, R85.2, R86.2, R87.2, R90.2, R92.2, U36.17, U36.36, U36.44, U37.5, U40.3, U40.7, U40.8
3.3V8: C113.1, C116.1, C120.1, C121.1, C125.1, C126.1, D63.1, J26.2, JP25.1, JP26.3.3V, JP26.IOREF, JP26.VCC, L9.1, R97.2, R98.2, R99.2, R102.2, R104.2, U41.17, U41.36, U41.44, U42.5, U45.3, U45.7, U45.8
!RESET: JP6.10, JP7.RESET@1, JP7.RESET@2, R11.1, S1.1, S1.2, U4.40
!RESET1: JP1.10, JP2.RESET@1, JP2.RESET@2, R13.1, S2.1, S2.2, U6.40
!RESET2: JP5.10, JP8.RESET@1, JP8.RESET@2, R25.1, S3.1, S3.2, U11.40
!RESET3: JP10.10, JP11.RESET@1, JP11.RESET@2, R37.1, S4.1, S4.2, U16.40
!RESET4: JP13.10, JP14.RESET@1, JP14.RESET@2, R49.1, S5.1, S5.2, U21.40
!RESET5: JP16.10, JP17.RESET@1, JP17.RESET@2, R61.1, S6.1, S6.2, U26.40
!RESET6: JP19.10, JP20.RESET@1, JP20.RESET@2, R73.1, S7.1, S7.2, U31.40
!RESET7: JP22.10, JP23.RESET@1, JP23.RESET@2, R85.1, S8.1, S8.2, U36.40
!RESET8: JP25.10, JP26.RESET@1, JP26.RESET@2, R97.1, S9.1, S9.2, U41.40
A0: JP7.A0, U4.3
A1: JP7.A1, U4.7
A2: JP7.A2, U4.8
A3: JP7.A3, U4.9
A4: JP7.A4, U4.10
A5: JP7.A5, U4.47
A6: JP2.A3, U6.9
A7: JP2.A2, U6.8
A8: JP2.A1, U6.7
A9: JP2.A0, U6.3
A10: JP2.A4, U6.10
A11: JP2.A5, U6.47
A12: JP8.A3, U11.9
A13: JP8.A2, U11.8
A14: JP8.A1, U11.7
A15: JP8.A0, U11.3
A16: JP8.A4, U11.10
A17: JP8.A5, U11.47
A18: JP11.A3, U16.9
A19: JP11.A2, U16.8
A20: JP11.A1, U16.7
A21: JP11.A0, U16.3
A22: JP11.A4, U16.10
A23: JP11.A5, U16.47
A24: JP14.A3, U21.9
A25: JP14.A2, U21.8
A26: JP14.A1, U21.7
A27: JP14.A0, U21.3
A28: JP14.A4, U21.10
A29: JP14.A5, U21.47
A30: JP17.A3, U26.9
A31: JP17.A2, U26.8
A32: JP17.A1, U26.7
A33: JP17.A0, U26.3
A34: JP17.A4, U26.10
A35: JP17.A5, U26.47
A36: JP20.A3, U31.9
A37: JP20.A2, U31.8
A38: JP20.A1, U31.7
A39: JP20.A0, U31.3
A40: JP20.A4, U31.10
A41: JP20.A5, U31.47
A42: JP23.A3, U36.9
A43: JP23.A2, U36.8
A44: JP23.A1, U36.7
A45: JP23.A0, U36.3
A46: JP23.A4, U36.10
A47: JP23.A5, U36.47
A48: JP26.A3, U41.9
A49: JP26.A2, U41.8
A50: JP26.A1, U41.7
A51: JP26.A0, U41.3
A52: JP26.A4, U41.10
A53: JP26.A5, U41.47
AREF: JP7.AREF, U4.4
AREF1: JP2.AREF, U6.4
AREF2: JP8.AREF, U11.4
AREF3: JP11.AREF, U16.4
AREF4: JP14.AREF, U21.4
AREF5: JP17.AREF, U26.4
AREF6: JP20.AREF, U31.4
AREF7: JP23.AREF, U36.4
AREF8: JP26.AREF, U41.4
CHG_STAT: R6.2, U1.1
CHG_STAT1: R22.2, U9.1
CHG_STAT2: R34.2, U14.1
CHG_STAT3: R46.2, U19.1
CHG_STAT4: R58.2, U24.1
CHG_STAT5: R70.2, U29.1
CHG_STAT6: R82.2, U34.1
CHG_STAT7: R94.2, U39.1
CHG_STAT8: R106.2, U44.1
D0/RXI: JP7.D0, U4.16
D0/RXI1: JP2.D0, U6.16
D0/RXI2: JP8.D0, U11.16
D0/RXI3: JP11.D0, U16.16
D0/RXI4: JP14.D0, U21.16
D0/RXI5: JP17.D0, U26.16
D0/RXI6: JP20.D0, U31.16
D0/RXI7: JP23.D0, U36.16
D0/RXI8: JP26.D0, U41.16
D1: JP2.D4, U6.13
D1/TXO: JP7.D1, U4.15
D1/TXO1: JP2.D1, U6.15
D1/TXO2: JP8.D1, U11.15
D1/TXO3: JP11.D1, U16.15
D1/TXO4: JP14.D1, U21.15
D1/TXO5: JP17.D1, U26.15
D1/TXO6: JP20.D1, U31.15
D1/TXO7: JP23.D1, U36.15
D1/TXO8: JP26.D1, U41.15
D2: JP7.D2, U4.23
D3: JP7.D3, U4.14
D4: JP7.D4, U4.13
D5: JP7.D5, U4.24
D6: JP7.D6, U4.29
D7: JP7.D7, U4.30
D8: JP7.D8, U4.11
D9: JP7.D9, U4.12
D10: JP7.D10, U4.27
D11: JP7.D11, U4.25
D12: JP7.D12, U4.28
D13: JP7.D13, Q2.1, R12.2, U4.26
D14: JP2.D3, U6.14
D15: JP2.D2, U6.23
D16: JP2.D5, U6.24
D17: JP2.D6, U6.29
D18: JP2.D7, U6.30
D19: JP2.D8, U6.11
D20: JP2.D9, U6.12
D21: JP2.D12, U6.28
D22: JP2.D11, U6.25
D23: JP2.D10, U6.27
D24: JP2.D13, Q3.1, R24.2, U6.26
D25: JP8.D4, U11.13
D26: JP8.D3, U11.14
D27: JP8.D2, U11.23
D28: JP8.D5, U11.24
D29: JP8.D6, U11.29
D30: JP8.D7, U11.30
D31: JP8.D8, U11.11
D32: JP8.D9, U11.12
D33: JP8.D12, U11.28
D34: JP8.D11, U11.25
D35: JP8.D10, U11.27
D36: JP8.D13, Q5.1, R36.2, U11.26
D37: JP11.D4, U16.13
D38: JP11.D3, U16.14
D39: JP11.D2, U16.23
D40: JP11.D5, U16.24
D41: JP11.D6, U16.29
D42: JP11.D7, U16.30
D43: JP11.D8, U16.11
D44: JP11.D9, U16.12
D45: JP11.D12, U16.28
D46: JP11.D11, U16.25
D47: JP11.D10, U16.27
D48: JP11.D13, Q7.1, R48.2, U16.26
D49: JP14.D4, U21.13
D50: JP14.D3, U21.14
D51: JP14.D2, U21.23
D52: JP14.D5, U21.24
D53: JP14.D6, U21.29
D54: JP14.D7, U21.30
D55: JP14.D8, U21.11
D56: JP14.D9, U21.12
D57: JP14.D12, U21.28
D58: JP14.D11, U21.25
D59: JP14.D10, U21.27
D60: JP14.D13, Q9.1, R60.2, U21.26
D61: JP17.D4, U26.13
D62: JP17.D3, U26.14
D63: JP17.D2, U26.23
D64: JP17.D5, U26.24
D65: JP17.D6, U26.29
D66: JP17.D7, U26.30
D67: JP17.D8, U26.11
D68: JP17.D9, U26.12
D69: JP17.D12, U26.28
D70: JP17.D11, U26.25
D71: JP17.D10, U26.27
D72: JP17.D13, Q11.1, R72.2, U26.26
D73: JP20.D4, U31.13
D74: JP20.D3, U31.14
D75: JP20.D2, U31.23
D76: JP20.D5, U31.24
D77: JP20.D6, U31.29
D78: JP20.D7, U31.30
D79: JP20.D8, U31.11
D80: JP20.D9, U31.12
D81: JP20.D12, U31.28
D82: JP20.D11, U31.25
D83: JP20.D10, U31.27
D84: JP20.D13, Q13.1, R84.2, U31.26
D85: JP23.D4, U36.13
D86: JP23.D3, U36.14
D87: JP23.D2, U36.23
D88: JP23.D5, U36.24
D89: JP23.D6, U36.29
D90: JP23.D7, U36.30
D91: JP23.D8, U36.11
D92: JP23.D9, U36.12
D93: JP23.D12, U36.28
D94: JP23.D11, U36.25
D95: JP23.D10, U36.27
D96: JP23.D13, Q15.1, R96.2, U36.26
D97: JP26.D4, U41.13
D98: JP26.D3, U41.14
D99: JP26.D2, U41.23
D100: JP26.D5, U41.24
D101: JP26.D6, U41.29
D102: JP26.D7, U41.30
D103: JP26.D8, U41.11
D104: JP26.D9, U41.12
D105: JP26.D12, U41.28
D106: JP26.D11, U41.25
D107: JP26.D10, U41.27
D108: JP26.D13, Q17.1, R108.2, U41.26
FLASH_CS: U4.22, U5.1
FLASH_CS1: U6.22, U10.1
FLASH_CS2: U11.22, U15.1
FLASH_CS3: U16.22, U20.1
FLASH_CS4: U21.22, U25.1
FLASH_CS5: U26.22, U30.1
FLASH_CS6: U31.22, U35.1
FLASH_CS7: U36.22, U40.1
FLASH_CS8: U41.22, U45.1
FLASH_MISO: U4.48, U5.2
FLASH_MISO1: U6.48, U10.2
FLASH_MISO2: U11.48, U15.2
FLASH_MISO3: U16.48, U20.2
FLASH_MISO4: U21.48, U25.2
FLASH_MISO5: U26.48, U30.2
FLASH_MISO6: U31.48, U35.2
FLASH_MISO7: U36.48, U40.2
FLASH_MISO8: U41.48, U45.2
FLASH_MOSI: U4.37, U5.5
FLASH_MOSI1: U6.37, U10.5
FLASH_MOSI2: U11.37, U15.5
FLASH_MOSI3: U16.37, U20.5
FLASH_MOSI4: U21.37, U25.5
FLASH_MOSI5: U26.37, U30.5
FLASH_MOSI6: U31.37, U35.5
FLASH_MOSI7: U36.37, U40.5
FLASH_MOSI8: U41.37, U45.5
FLASH_SCK: U4.38, U5.6
FLASH_SCK1: U6.38, U10.6
FLASH_SCK2: U11.38, U15.6
FLASH_SCK3: U16.38, U20.6
FLASH_SCK4: U21.38, U25.6
FLASH_SCK5: U26.38, U30.6
FLASH_SCK6: U31.38, U35.6
FLASH_SCK7: U36.38, U40.6
FLASH_SCK8: U41.38, U45.6
GND: C1.2, C2.2, C3.2, C4.2, C5.2, C6.2, C7.2, C8.2, C9.1, C10.2, C11.2, C12.2, C13.2, C14.2, D7.3, J1.1, J2.1, J3.GND, J3.SHIELD, J3.SHIELD2, J3.SHIELD3, J3.SHIELD4, J3.SHIELD5, J3.SHIELD6, J3.SHIELD7, J3.SHIELD8, J3.SHIELD9, J3.SHIELD10, JP3.GND, JP3.GNDBREAK, JP6.3, JP6.5, JP7.GND@1, JP7.GND@2, JP7.GND@3, JP7.GND@4, Q2.2, R1.1, R3.1, R12.1, S1.3, S1.4, SJ1.1, U1.2, U2.3, U3.2, U4.5, U4.18, U4.35, U4.42, U5.4
GND1: C15.2, C16.2, C17.2, C18.2, C19.1, C20.2, C21.2, C22.2, C23.2, C24.2, C25.2, C26.2, C27.2, C28.2, D14.3, J4.1, J5.1, J6.GND, J6.SHIELD, J6.SHIELD2, J6.SHIELD3, J6.SHIELD4, J6.SHIELD5, J6.SHIELD6, J6.SHIELD7, J6.SHIELD8, J6.SHIELD9, J6.SHIELD10, JP1.3, JP1.5, JP2.GND@1, JP2.GND@2, JP2.GND@3, JP2.GND@4, JP4.GND, JP4.GNDBREAK, Q3.2, R21.1, R23.1, R24.1, S2.3, S2.4, SJ2.1, U6.5, U6.18, U6.35, U6.42, U7.2, U8.3, U9.2, U10.4
GND2: C29.2, C30.2, C31.2, C32.2, C33.1, C34.2, C35.2, C36.2, C37.2, C38.2, C39.2, C40.2, C41.2, C42.2, D21.3, J7.1, J8.1, J9.GND, J9.SHIELD, J9.SHIELD2, J9.SHIELD3, J9.SHIELD4, J9.SHIELD5, J9.SHIELD6, J9.SHIELD7, J9.SHIELD8, J9.SHIELD9, J9.SHIELD10, JP5.3, JP5.5, JP8.GND@1, JP8.GND@2, JP8.GND@3, JP8.GND@4, JP9.GND, JP9.GNDBREAK, Q5.2, R33.1, R35.1, R36.1, S3.3, S3.4, SJ3.1, U11.5, U11.18, U11.35, U11.42, U12.2, U13.3, U14.2, U15.4
GND3: C43.2, C44.2, C45.2, C46.2, C47.1, C48.2, C49.2, C50.2, C51.2, C52.2, C53.2, C54.2, C55.2, C56.2, D28.3, J10.1, J11.1, J12.GND, J12.SHIELD, J12.SHIELD2, J12.SHIELD3, J12.SHIELD4, J12.SHIELD5, J12.SHIELD6, J12.SHIELD7, J12.SHIELD8, J12.SHIELD9, J12.SHIELD10, JP10.3, JP10.5, JP11.GND@1, JP11.GND@2, JP11.GND@3, JP11.GND@4, JP12.GND, JP12.GNDBREAK, Q7.2, R45.1, R47.1, R48.1, S4.3, S4.4, SJ4.1, U16.5, U16.18, U16.35, U16.42, U17.2, U18.3, U19.2, U20.4
GND4: C57.2, C58.2, C59.2, C60.2, C61.1, C62.2, C63.2, C64.2, C65.2, C66.2, C67.2, C68.2, C69.2, C70.2, D35.3, J13.1, J14.1, J15.GND, J15.SHIELD, J15.SHIELD2, J15.SHIELD3, J15.SHIELD4, J15.SHIELD5, J15.SHIELD6, J15.SHIELD7, J15.SHIELD8, J15.SHIELD9, J15.SHIELD10, JP13.3, JP13.5, JP14.GND@1, JP14.GND@2, JP14.GND@3, JP14.GND@4, JP15.GND, JP15.GNDBREAK, Q9.2, R57.1, R59.1, R60.1, S5.3, S5.4, SJ5.1, U21.5, U21.18, U21.35, U21.42, U22.2, U23.3, U24.2, U25.4
GND5: C71.2, C72.2, C73.2, C74.2, C75.1, C76.2, C77.2, C78.2, C79.2, C80.2, C81.2, C82.2, C83.2, C84.2, D42.3, J16.1, J17.1, J18.GND, J18.SHIELD, J18.SHIELD2, J18.SHIELD3, J18.SHIELD4, J18.SHIELD5, J18.SHIELD6, J18.SHIELD7, J18.SHIELD8, J18.SHIELD9, J18.SHIELD10, JP16.3, JP16.5, JP17.GND@1, JP17.GND@2, JP17.GND@3, JP17.GND@4, JP18.GND, JP18.GNDBREAK, Q11.2, R69.1, R71.1, R72.1, S6.3, S6.4, SJ6.1, U26.5, U26.18, U26.35, U26.42, U27.2, U28.3, U29.2, U30.4
GND6: C85.2, C86.2, C87.2, C88.2, C89.1, C90.2, C91.2, C92.2, C93.2, C94.2, C95.2, C96.2, C97.2, C98.2, D49.3, J19.1, J20.1, J21.GND, J21.SHIELD, J21.SHIELD2, J21.SHIELD3, J21.SHIELD4, J21.SHIELD5, J21.SHIELD6, J21.SHIELD7, J21.SHIELD8, J21.SHIELD9, J21.SHIELD10, JP19.3, JP19.5, JP20.GND@1, JP20.GND@2, JP20.GND@3, JP20.GND@4, JP21.GND, JP21.GNDBREAK, Q13.2, R81.1, R83.1, R84.1, S7.3, S7.4, SJ7.1, U31.5, U31.18, U31.35, U31.42, U32.2, U33.3, U34.2, U35.4
GND7: C99.2, C100.2, C101.2, C102.2, C103.1, C104.2, C105.2, C106.2, C107.2, C108.2, C109.2, C110.2, C111.2, C112.2, D56.3, J22.1, J23.1, J24.GND, J24.SHIELD, J24.SHIELD2, J24.SHIELD3, J24.SHIELD4, J24.SHIELD5, J24.SHIELD6, J24.SHIELD7, J24.SHIELD8, J24.SHIELD9, J24.SHIELD10, JP22.3, JP22.5, JP23.GND@1, JP23.GND@2, JP23.GND@3, JP23.GND@4, JP24.GND, JP24.GNDBREAK, Q15.2, R93.1, R95.1, R96.1, S8.3, S8.4, SJ8.1, U36.5, U36.18, U36.35, U36.42, U37.2, U38.3, U39.2, U40.4
GND8: C113.2, C114.2, C115.2, C116.2, C117.1, C118.2, C119.2, C120.2, C121.2, C122.2, C123.2, C124.2, C125.2, C126.2, D63.3, J25.1, J26.1, J27.GND, J27.SHIELD, J27.SHIELD2, J27.SHIELD3, J27.SHIELD4, J27.SHIELD5, J27.SHIELD6, J27.SHIELD7, J27.SHIELD8, J27.SHIELD9, J27.SHIELD10, JP25.3, JP25.5, JP26.GND@1, JP26.GND@2, JP26.GND@3, JP26.GND@4, JP27.GND, JP27.GNDBREAK, Q17.2, R105.1, R107.1, R108.1, S9.3, S9.4, SJ9.1, U41.5, U41.18, U41.35, U41.42, U42.2, U43.3, U44.2, U45.4
LED/SWCLK: D7.4, JP6.4, U4.45
LED/SWCLK1: D14.4, JP1.4, U6.45
LED/SWCLK2: D21.4, JP5.4, U11.45
LED/SWCLK3: D28.4, JP10.4, U16.45
LED/SWCLK4: D35.4, JP13.4, U21.45
LED/SWCLK5: D42.4, JP16.4, U26.45
LED/SWCLK6: D49.4, JP19.4, U31.45
LED/SWCLK7: D56.4, JP22.4, U36.45
LED/SWCLK8: D63.4, JP25.4, U41.45
unnamed: F1.1, J3.VBUS
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

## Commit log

2018-06-22 Initial revision changes
    [sparkfun-samd21-pro-breakout.brd, sparkfun-samd21-pro-breakout.sch]
2018-06-22 Changed to RedBoard Turbo
    [RedBoard_Turbo.brd, RedBoard_Turbo.sch]
2018-06-22 Added board title
    [RedBoard_Turbo.brd]
2018-06-25 Add testpoint and label for LED
    [RedBoard_Turbo.brd, RedBoard_Turbo.sch]
2018-06-25 Changes from review
    [RedBoard_Turbo.brd, RedBoard_Turbo.sch]
2018-06-27 Change name on schematic
    [RedBoard_Turbo.brd, RedBoard_Turbo.sch]
2018-06-27 Add polarity markings to JST connector
    [RedBoard_Turbo.brd, RedBoard_Turbo.sch]
2018-07-09 Updated 0805 cap, approved DRC errors
    [RedBoard_Turbo.brd, RedBoard_Turbo.sch]
2018-12-04 v20
    Updated silk
    [RedBoard_Turbo.brd, RedBoard_Turbo.sch]
2018-12-06 Design Review Changes
    - Switched board version to v10
    - Changed RED charge LED to yellow
    - Updated power LED silk
    - Added barrel jack max voltage silk
    - Replaced reset button with larger button and longer actuator
    [RedBoard_Turbo.brd, RedBoard_Turbo.sch]
2018-12-06 Updated schematic
    Updated part names and removed extra text
    [RedBoard_Turbo.brd, RedBoard_Turbo.sch]
2019-01-24 Release Update
    -Updated README
    - Added .svg and .pdf graphical datasheets
    - Added .bin,.elf,.uf2 bootloader firmware
    - Added circuit python uf2 file
2021-01-14 Fix Minor Error in RedBoard Turbo SAMD21
    User found a minor error with a pin for the RedBoard Turbo SAMD21 => #4
    "GraphicalDatasheet-SamD21TurboDev.pdf should show RX_LED attached to pin PA31 not PB03. Schematic file shows RX_LED attached to pin PA31."
    It was verified and corrected. The pin characteristics were also updated with respect to the pin. Product page's documents and tutorial have been updated as well.

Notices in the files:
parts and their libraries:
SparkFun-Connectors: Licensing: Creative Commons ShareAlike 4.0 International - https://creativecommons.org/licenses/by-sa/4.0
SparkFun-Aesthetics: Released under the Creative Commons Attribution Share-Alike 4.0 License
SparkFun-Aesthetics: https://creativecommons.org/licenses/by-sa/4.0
